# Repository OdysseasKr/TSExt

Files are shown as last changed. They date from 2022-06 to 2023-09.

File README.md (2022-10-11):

# TSExt
## A 3D-printed hand-wired split keyboard inspired from TS65

This is my attempt at designing an extended version of the [TS65](https://github.com/mohitg11/TS65AVR). The main motivation is that I wanted more keys and the ability to hand solder everything instead of making a PCB. The keyboard is powered by [QMK](https://qmk.fm/).

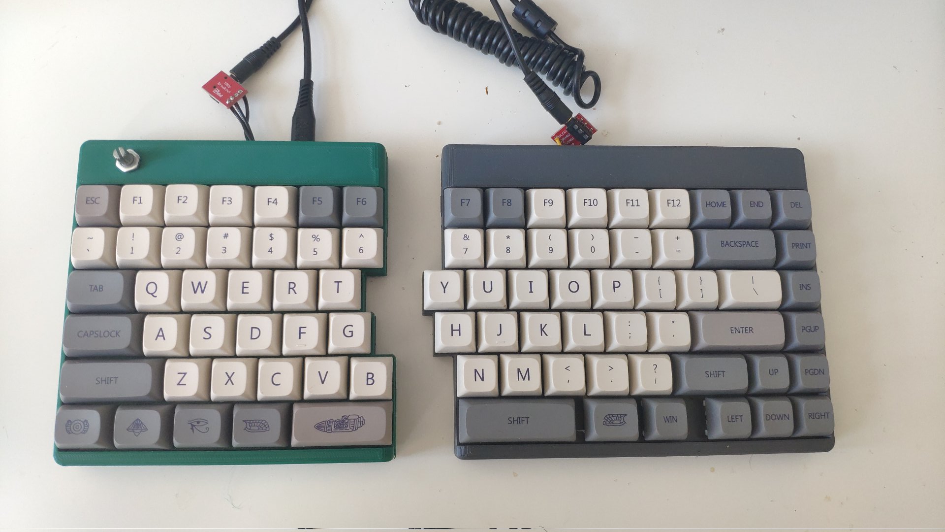
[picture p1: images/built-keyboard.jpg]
Built keyboard


Please note that this is a rough design that I made for personal use and most probably you will need to adjust a bit (adjust screw sizes, make holes for connectors etc).

[Keyboard layout permalink](http://www.keyboard-layout-editor.com/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'&_w:2.25%3B&=Enter&=PgUp%3B&@_w:2.25%3B&=Shift&=Z&=X&=C&=V&=B&_x:1%3B&=N&=M&=%3C%0A,&=%3E%0A.&=%3F%0A%2F%2F&_w:1.75%3B&=Shift&=%E2%86%91&=PgDn%3B&@_w:1.25%3B&=Ctrl&_w:1.25%3B&=Fn&_w:1.25%3B&=Win&_w:1.25%3B&=Alt&_a:7&w:2.25%3B&=&_x:1&w:2.75%3B&=&_a:4&w:1.25%3B&=Alt&_w:1.25%3B&=Win&_x:0.5%3B&=%E2%86%90&=%E2%86%93&=%E2%86%92)

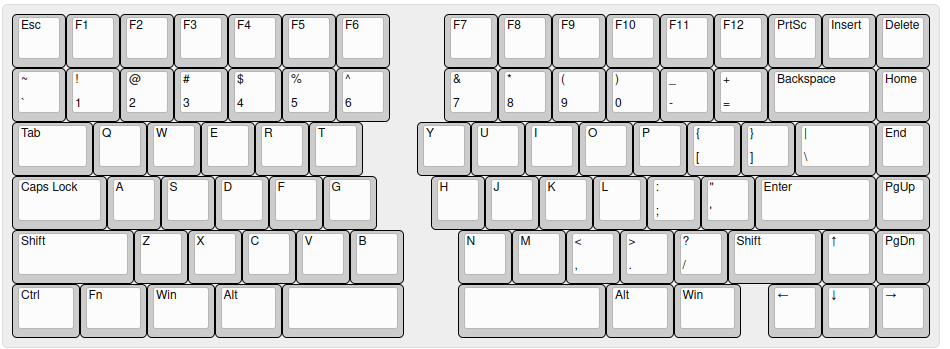
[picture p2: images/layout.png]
Layout


The changes I have made are:

- Added an extra row for F-keys
- An extra column for Home,End,PgUp and PgDown
- Redesigned the plate to allow for switch mounting
- Added some extra space on the top of the keyboard to house all the electronics
- Added an Fn key
- Added a rotary encoder on the left side

Some models are adaptation from this [design on Thingiverse](https://www.thingiverse.com/thing:3027838) made by [Adam Coddington](https://www.thingiverse.com/coddingtonbear).

## How to build
### Materials
1. About 300 grams of material
2. 30 hours of print time (on an Ender 3)
3. 11 M2x10 screws and 4x4x6 brass heat inserts
4. 2 Arduino Pro-micro
5. A USB2.0 breakout board or some other way to extend the micro usb port of the Arduino
6. 85 Cherry MX switches and keycaps
7. 85 diodes 1n4148 (or equivalent)
8. 7mm wider rotary encoder

### Printing the case
Printing the case should be simple but takes some time. No need for supports. I recommend adding a brim and lowering the fan to prevent warping.

**Top parts**: I used 100% infill to reduce flex as much as possible

**Bottom parts**: anything above 50% should work ok. The print time is almost the same regardless of the infill.

### Soldering
Follow the [QMK guide](https://docs.qmk.fm/#/hand_wire?id=soldering-the-diodes) for hand-wiring and soldering keyboards.

Wiring diagrams

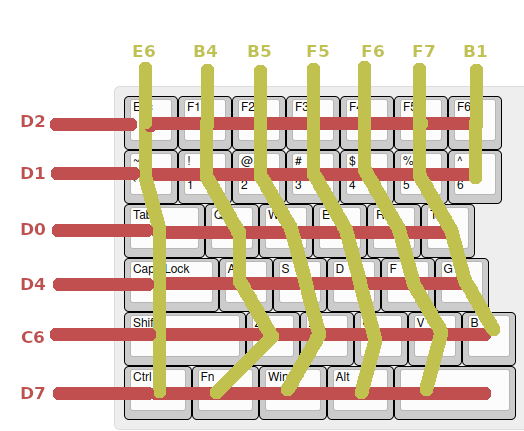
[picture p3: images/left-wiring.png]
Left

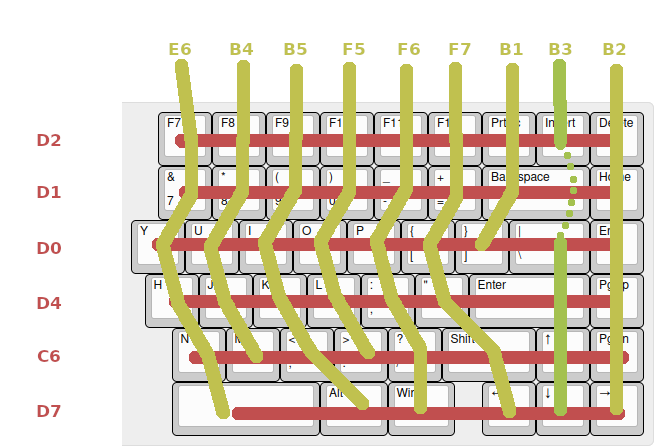
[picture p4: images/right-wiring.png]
Right


Note that on the right side, pin `B3` is connected to `Insert->Backslash->Enter->Up->Down` and *NOT* backspace.

The pin for serial communication between the left and right Arduinos is `D3`

The rotary encoder on the left half is connected to pins `B2` and `B6`. 

### Flashing
There are two Arduinos in total, one for each side. Each arduino needs to be flashed with their own qmk firmware. To do this you will need a local installation of [qmk-firmware](https://github.com/qmk/qmk_firmware/). 

To start flashing you keyboard, copy the *TSExt* folder from the *firmware* folder to *qmk_firmware/keyboards*. The directory structure should be

```
qmk_firmware
|
|-- keyboards
    |
    |-- TSExt
```

To flash the left Arduino
```
make ts_ext:avrdude-split-left 
```

and the right one
```
make ts_ext:avrdude-split-right
```

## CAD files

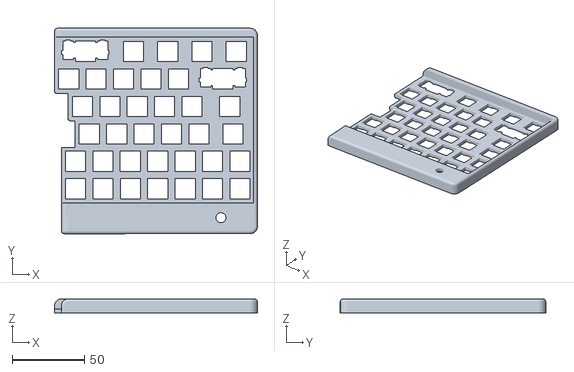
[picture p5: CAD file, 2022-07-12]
case/Left Top.stl
140.8 x 142.5 x 10.0

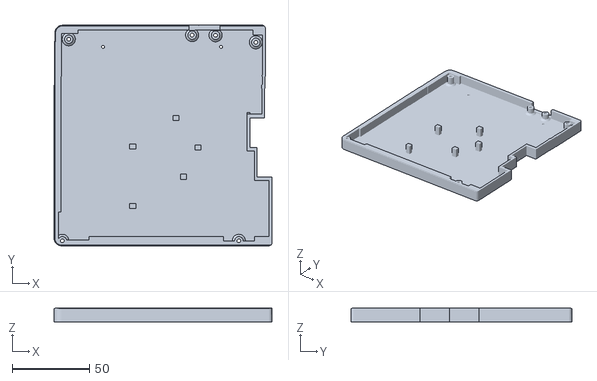
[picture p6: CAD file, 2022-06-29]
case/Left Bottom.stl
140.7 x 142.5 x 9.00

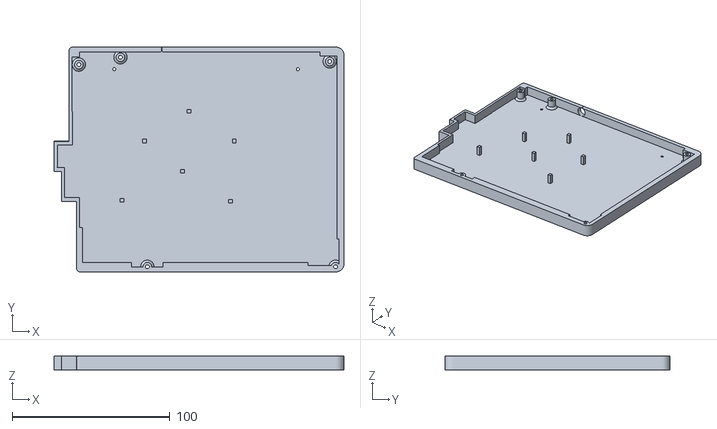
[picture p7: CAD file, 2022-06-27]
case/Right Bottom.stl
183.7 x 142.4 x 9.00

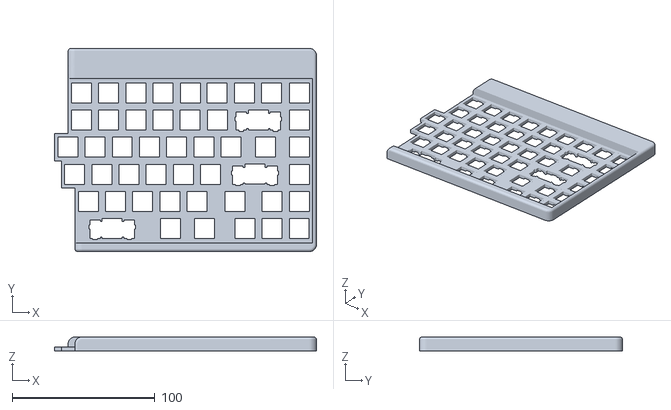
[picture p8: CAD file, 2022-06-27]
case/Right Top.stl
183.6 x 142.5 x 10.0

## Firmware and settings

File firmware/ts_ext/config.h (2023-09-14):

// Copyright 2022 OdysseasKr (@OdysseasKr)
// SPDX-License-Identifier: GPL-2.0-or-later

#pragma once

/*
 * Feature disable options
 *  These options are also useful to firmware size reduction.
 */

/* disable debug print */
//#define NO_DEBUG

/* disable print */
//#define NO_PRINT

/* disable action features */
//#define NO_ACTION_LAYER
//#define NO_ACTION_TAPPING
//#define NO_ACTION_ONESHOT
//#define BACKLIGHT_PIN B5
#define SOFT_SERIAL_PIN D3
#define EE_HANDS
#define MATRIX_ROWS 12
#define MATRIX_COLS 9
// The following line is only for my own build due to quirks in my pinout
// #define MATRIX_ROW_PINS { D2, B3, D0, D4, C6, D7 }
#define MATRIX_ROW_PINS { D2, D1, D0, D4, C6, D7 }
#define MATRIX_COL_PINS { E6, B4, B5, F5, F6, F7, B1 }
#define MATRIX_ROW_PINS_RIGHT { D2, D1, D0, D4, C6, D7 }
#define MATRIX_COL_PINS_RIGHT { E6, B4, B5, F5, F6, F7, B1, B3, B2 }
#define ENCODERS_PAD_A { B2 }
#define ENCODERS_PAD_B { B6 }

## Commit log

2022-06-27 Add stl files
    [Left top.stl, Right Bottom.stl, Right Top.stl]
2022-06-29 Add more designs
    [Left Bottom.stl, Left top.stl]
2022-07-01 Rename keyboard and swap home position
    [config.h]
2022-07-12 Added encoder on left side
2022-07-12 Update case and info for rotary encoder
    [Left Top.stl, Left top.stl]
2023-09-14 Remove unnecessary ENCODER_MAP_ENABLE
